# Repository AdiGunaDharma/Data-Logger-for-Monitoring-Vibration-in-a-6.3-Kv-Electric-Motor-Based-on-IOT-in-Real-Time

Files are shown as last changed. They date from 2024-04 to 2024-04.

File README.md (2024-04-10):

# Data-Logger-for-Monitoring-Vibration-in-a-6.3-Kv-Electric-Motor-Based-on-IOT-in-Real-Time
**Eagle Electronic Layout**
  1. Top Layout
Top Layout
  2. Bottom Layout
Bottom Layout
**Main**
  1. Vibration Measurement Points and Vibration Measurement Templates at Jeranjang PLTU

  2. Measurement Diagrams on Prototypes

  3. Arduino IDE Software Display and Blynk Application

  4. Sensor Data Amplifier Circuit

  5. Prototype Work System Flowchart


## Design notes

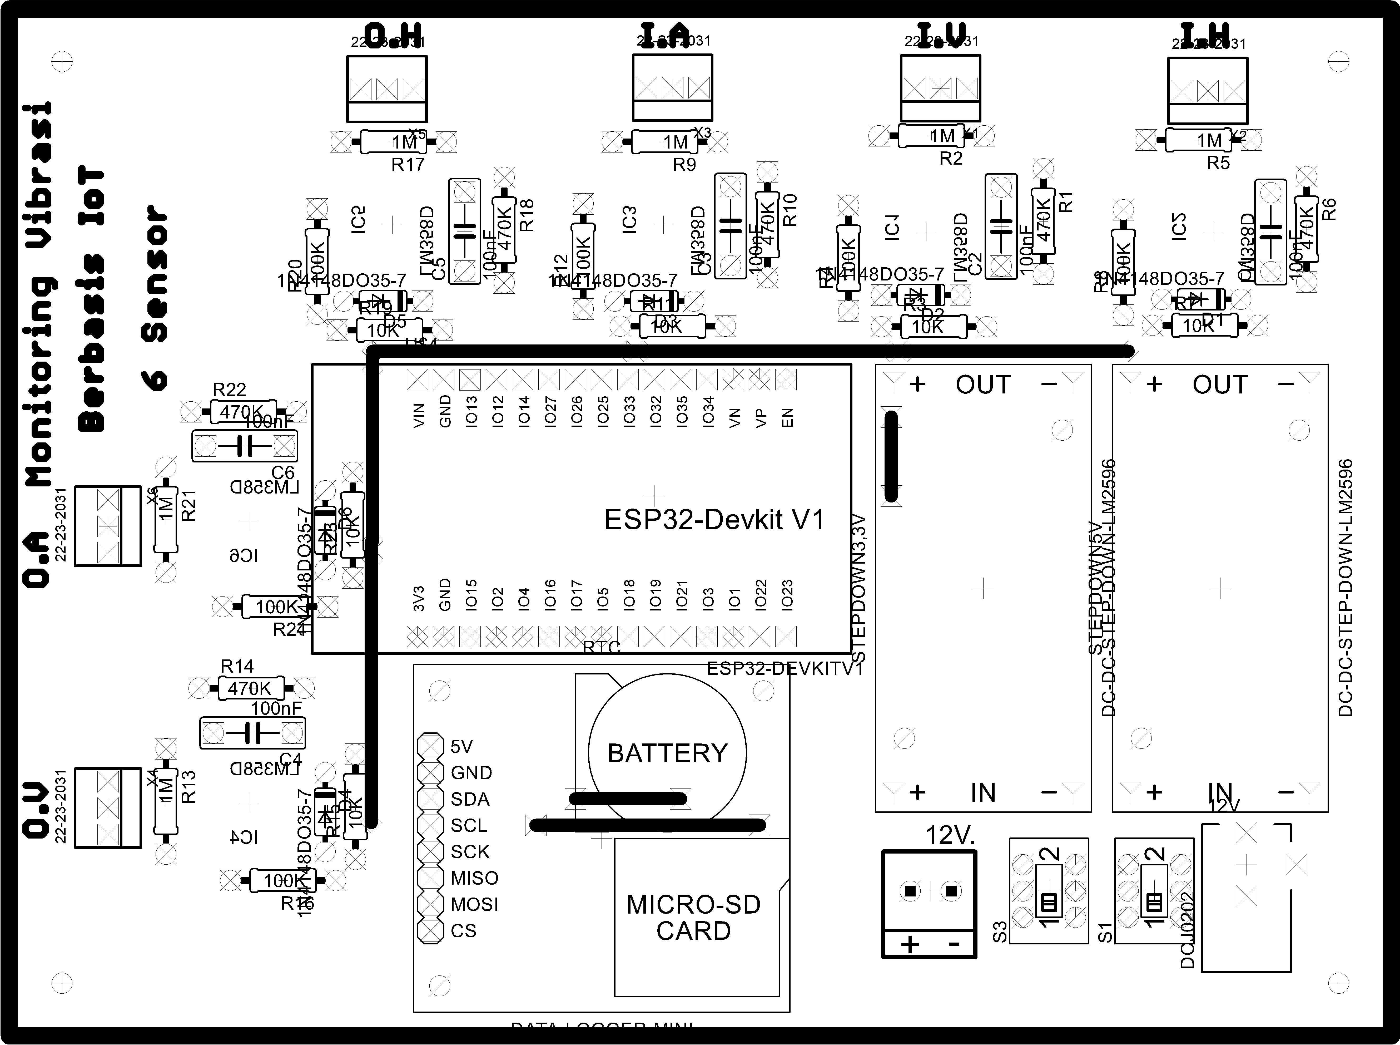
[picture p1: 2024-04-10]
Eagle Electronic Layout/Top Layout.png

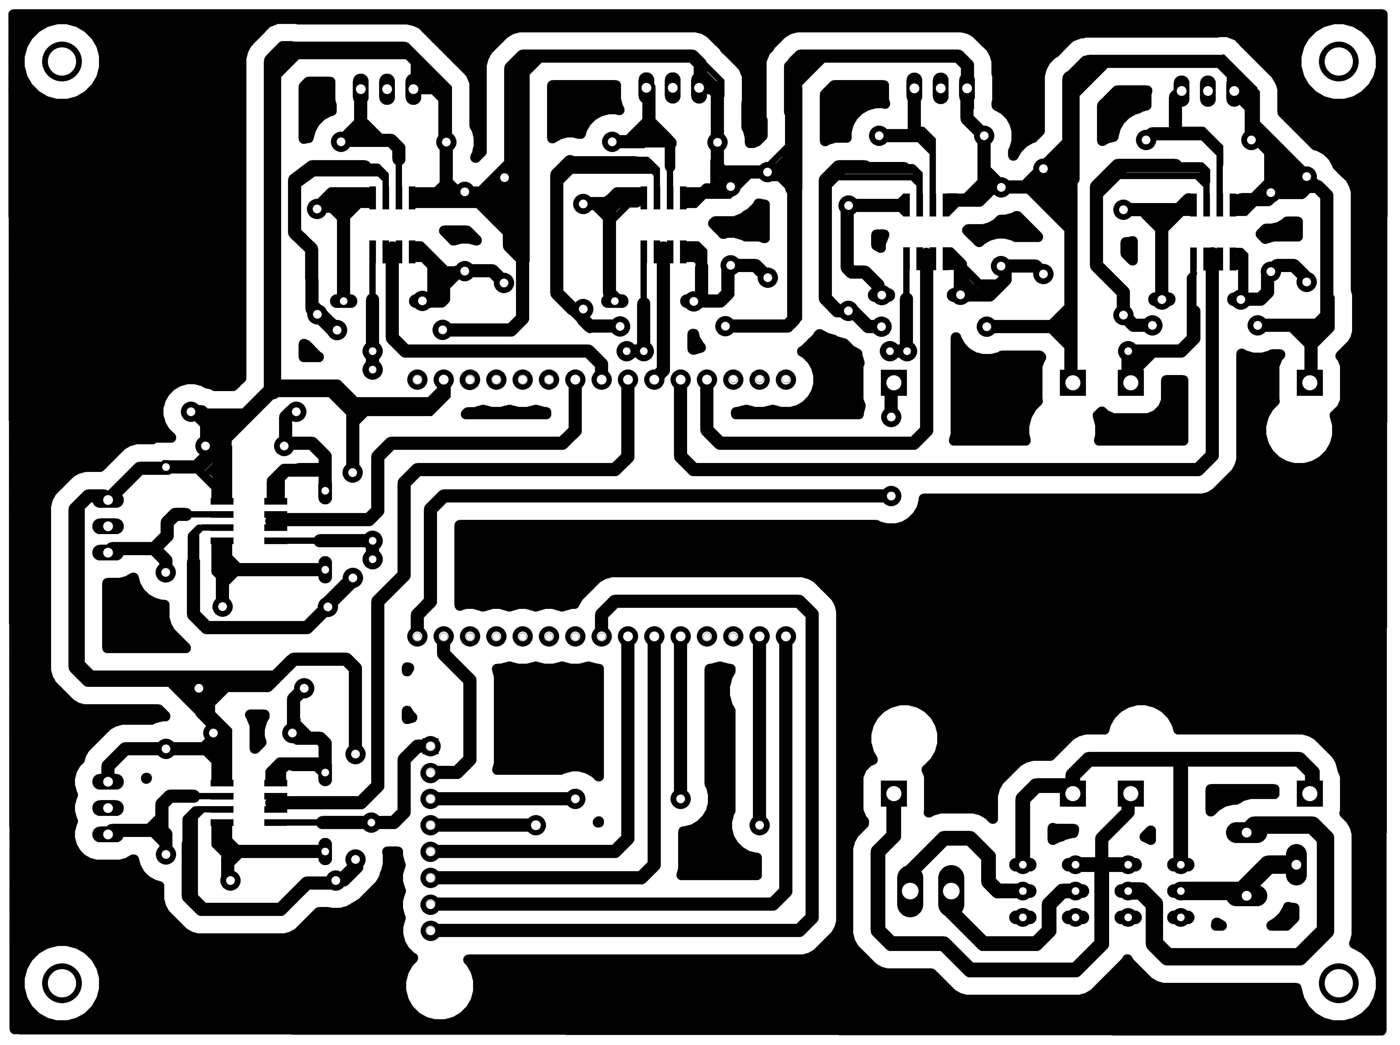
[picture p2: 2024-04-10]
Eagle Electronic Layout/Bottom Layout.png

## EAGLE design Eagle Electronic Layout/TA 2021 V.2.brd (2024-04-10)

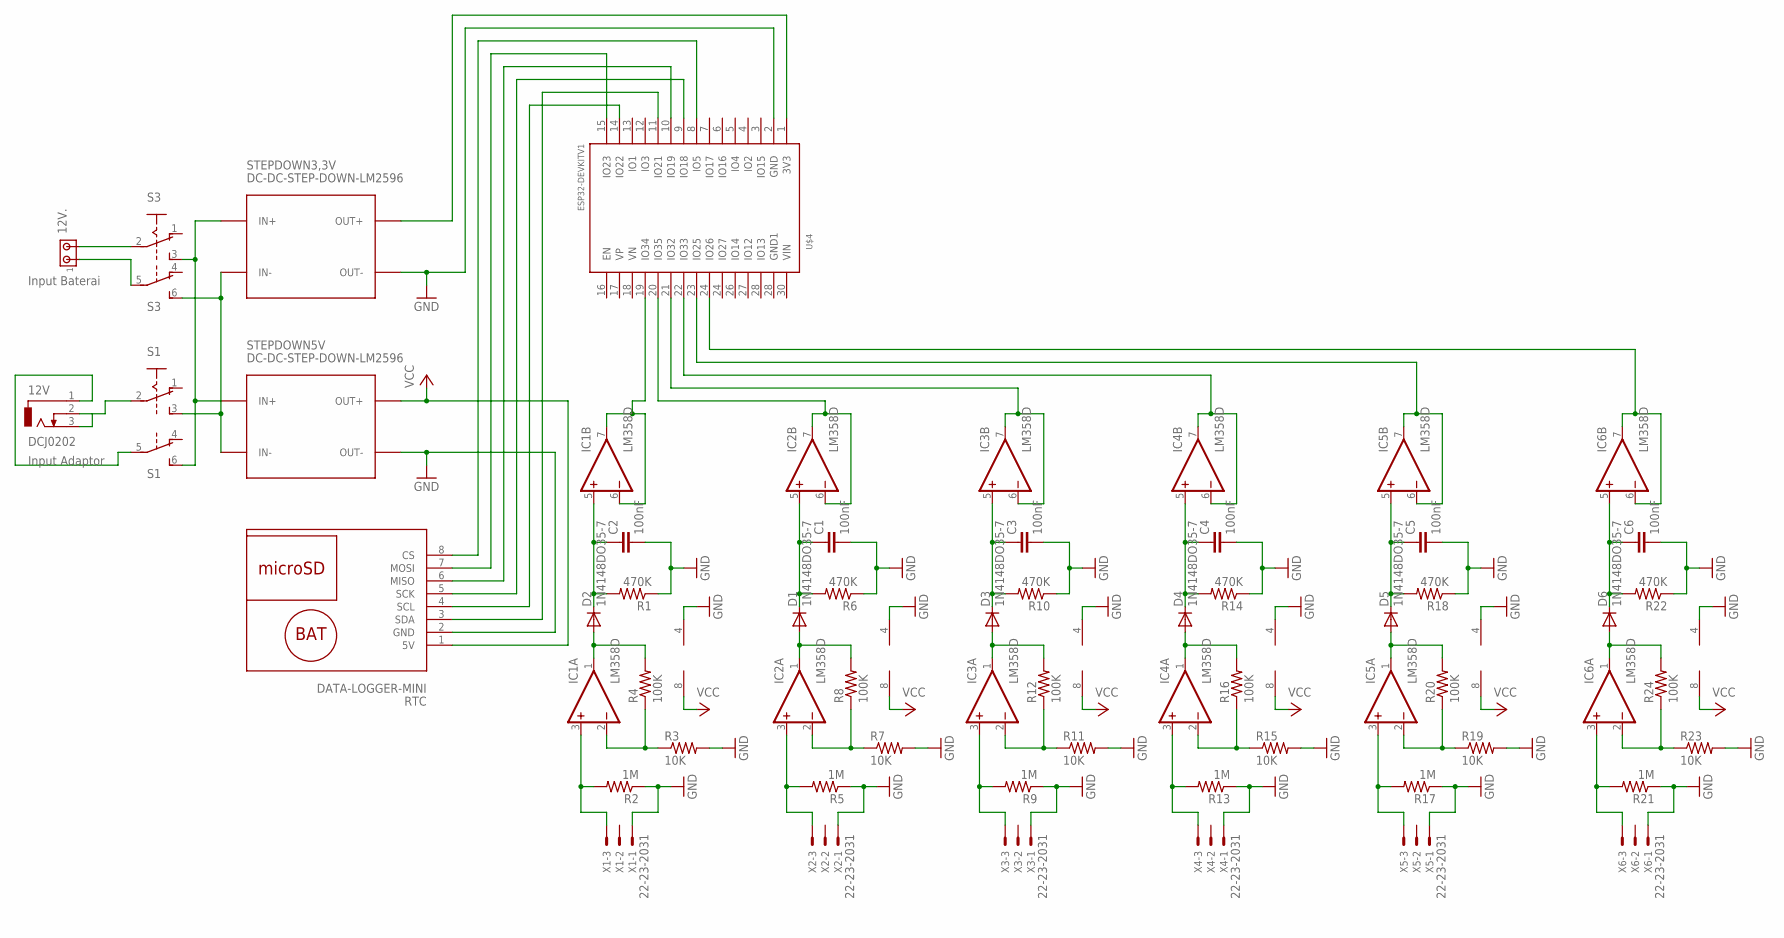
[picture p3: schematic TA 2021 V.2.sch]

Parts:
12V: DCJ0202
12V.: MTA02-156; 1X2MTA
C1, C2, C3, C4, C5, C6: 100nF; C075-032X103
D1, D2, D3, D4, D5, D6: 1N4148DO35-7; DO35-7
IC1, IC2, IC3, IC4, IC5, IC6: LM358D; SO08
R1, R6, R10, R14, R18, R22: 470K; 0207/10
R2, R5, R9, R13, R17, R21: 1M; 0207/10
R3, R7, R11, R15, R19, R23: 10K; 0207/10
R4, R8, R12, R16, R20, R24: 100K; 0207/10
RTC: DATA-LOGGER-MINI
S1, S3: A68-A31
STEPDOWN3,3V, STEPDOWN5V: DC-DC-STEP-DOWN-LM2596
U$4: ESP32DEVKITV1; ESP32-DEVKITV1
X1, X2, X3, X4, X5, X6: 22-23-2031

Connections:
unnamed: 12V..2, S3.2
unnamed: RTC.7 (MOSI), U$4.15 (IO23)
unnamed: S1.6 (S), S3.3 (S), STEPDOWN3,3V.IN+, STEPDOWN5V.IN+
unnamed: RTC.8 (CS), U$4.8 (IO5)
unnamed: 12V.2, 12V.3, S1.2
unnamed: RTC.6 (MISO), U$4.10 (IO19)
unnamed: 12V..1, S3.5
unnamed: RTC.5 (SCK), U$4.9 (IO18)
unnamed: 12V.1, S1.5
unnamed: C1.2, C2.2, C3.2, C4.2, C5.2, C6.2, IC1.4 (V-), IC2.4 (V-), IC3.4 (V-), IC4.4 (V-), IC5.4 (V-), IC6.4 (V-), R1.1, R2.1, R3.2, R5.1, R6.1, R7.2, R9.1, R10.1, R11.2, R13.1, R14.1, R15.2, R17.1, R18.1, R19.2, R21.1, R22.1, R23.2, RTC.2 (GND), STEPDOWN3,3V.OUT-, STEPDOWN5V.OUT-, U$4.2 (GND), X1.1, X2.1, X3.1, X4.1, X5.1, X6.1
unnamed: S1.3 (S), S3.6 (S), STEPDOWN3,3V.IN-, STEPDOWN5V.IN-
unnamed: IC2.6 (-IN), IC2.7 (OUT), U$4.20 (IO35)
unnamed: D1.A, IC2.1 (OUT), R8.2
unnamed: IC2.2 (-IN), R7.1, R8.1
unnamed: RTC.4 (SCL), U$4.14 (IO22)
unnamed: IC3.6 (-IN), IC3.7 (OUT), U$4.21 (IO32)
unnamed: STEPDOWN3,3V.OUT+, U$4.1 (3V3)
unnamed: IC4.6 (-IN), IC4.7 (OUT), U$4.22 (IO33)
unnamed: IC5.6 (-IN), IC5.7 (OUT), U$4.23 (IO25)
unnamed: IC6.6 (-IN), IC6.7 (OUT), U$4.24 (IO27)
unnamed: RTC.3 (SDA), U$4.11 (IO21)
unnamed: IC1.3 (+IN), R2.2, X1.3
unnamed: C1.1, D1.C, IC2.5 (+IN), R6.2
unnamed: D2.A, IC1.1 (OUT), R4.2
unnamed: IC1.2 (-IN), R3.1, R4.1
unnamed: C2.1, D2.C, IC1.5 (+IN), R1.2
unnamed: D4.A, IC4.1 (OUT), R16.2
unnamed: IC1.6 (-IN), IC1.7 (OUT), U$4.19 (IO34)
unnamed: IC2.3 (+IN), R5.2, X2.3
unnamed: D3.A, IC3.1 (OUT), R12.2
unnamed: C3.1, D3.C, IC3.5 (+IN), R10.2
unnamed: D6.A, IC6.1 (OUT), R24.2
unnamed: IC3.3 (+IN), R9.2, X3.3
unnamed: IC4.2 (-IN), R15.1, R16.1
unnamed: IC6.2 (-IN), R23.1, R24.1
unnamed: IC4.3 (+IN), R13.2, X4.3
unnamed: D5.A, IC5.1 (OUT), R20.2
unnamed: IC5.2 (-IN), R19.1, R20.1
unnamed: C5.1, D5.C, IC5.5 (+IN), R18.2
unnamed: IC5.3 (+IN), R17.2, X5.3
unnamed: IC6.3 (+IN), R21.2, X6.3
unnamed: IC3.2 (-IN), R11.1, R12.1
unnamed: C6.1, D6.C, IC6.5 (+IN), R22.2
unnamed: C4.1, D4.C, IC4.5 (+IN), R14.2
VCC: IC1.8 (V+), IC2.8 (V+), IC3.8 (V+), IC4.8 (V+), IC5.8 (V+), IC6.8 (V+), RTC.1 (5V), STEPDOWN5V.OUT+

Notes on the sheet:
Input Baterai
Input Adaptor

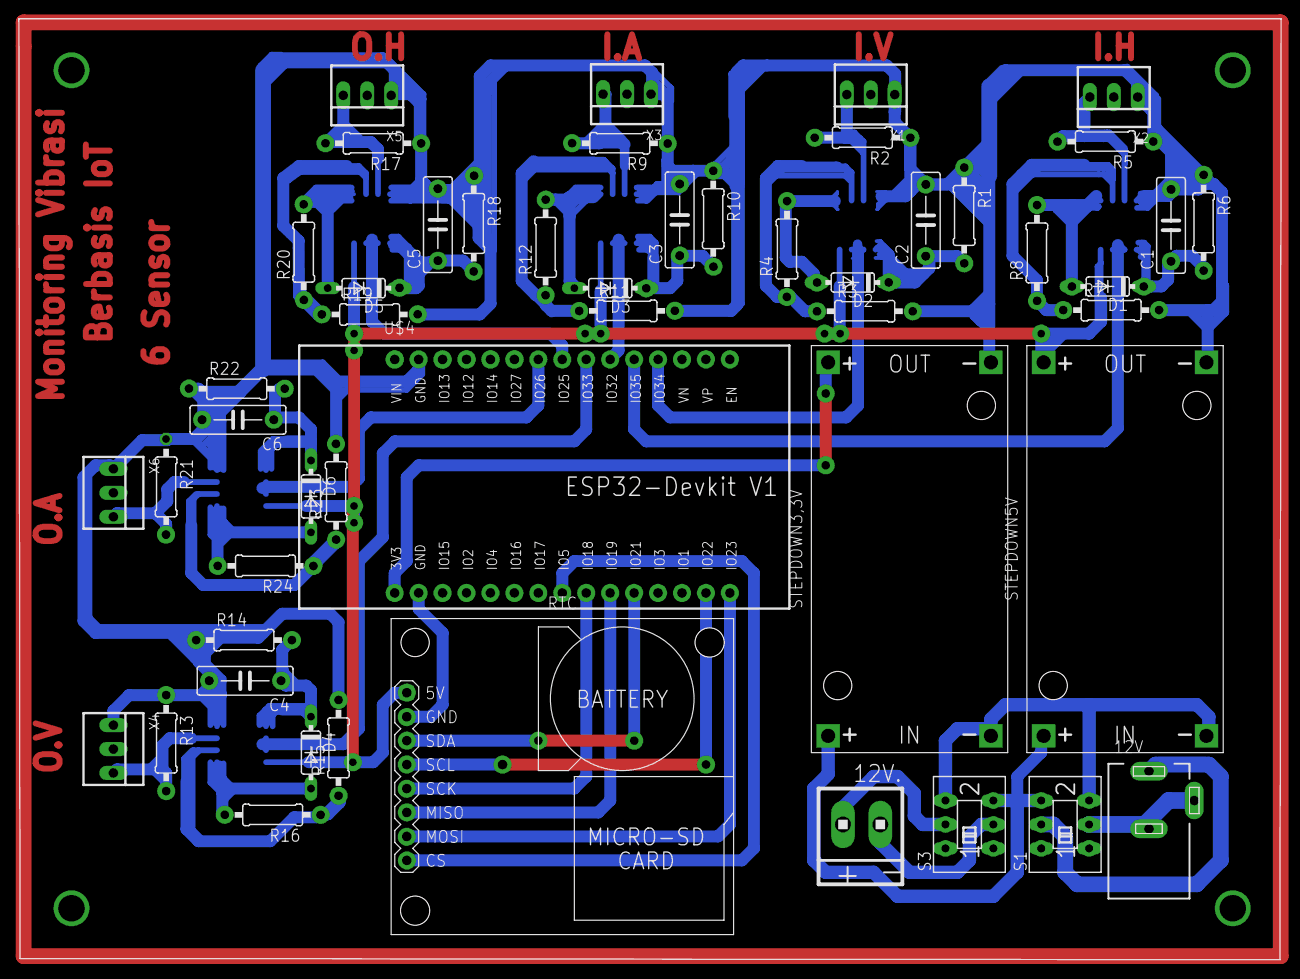
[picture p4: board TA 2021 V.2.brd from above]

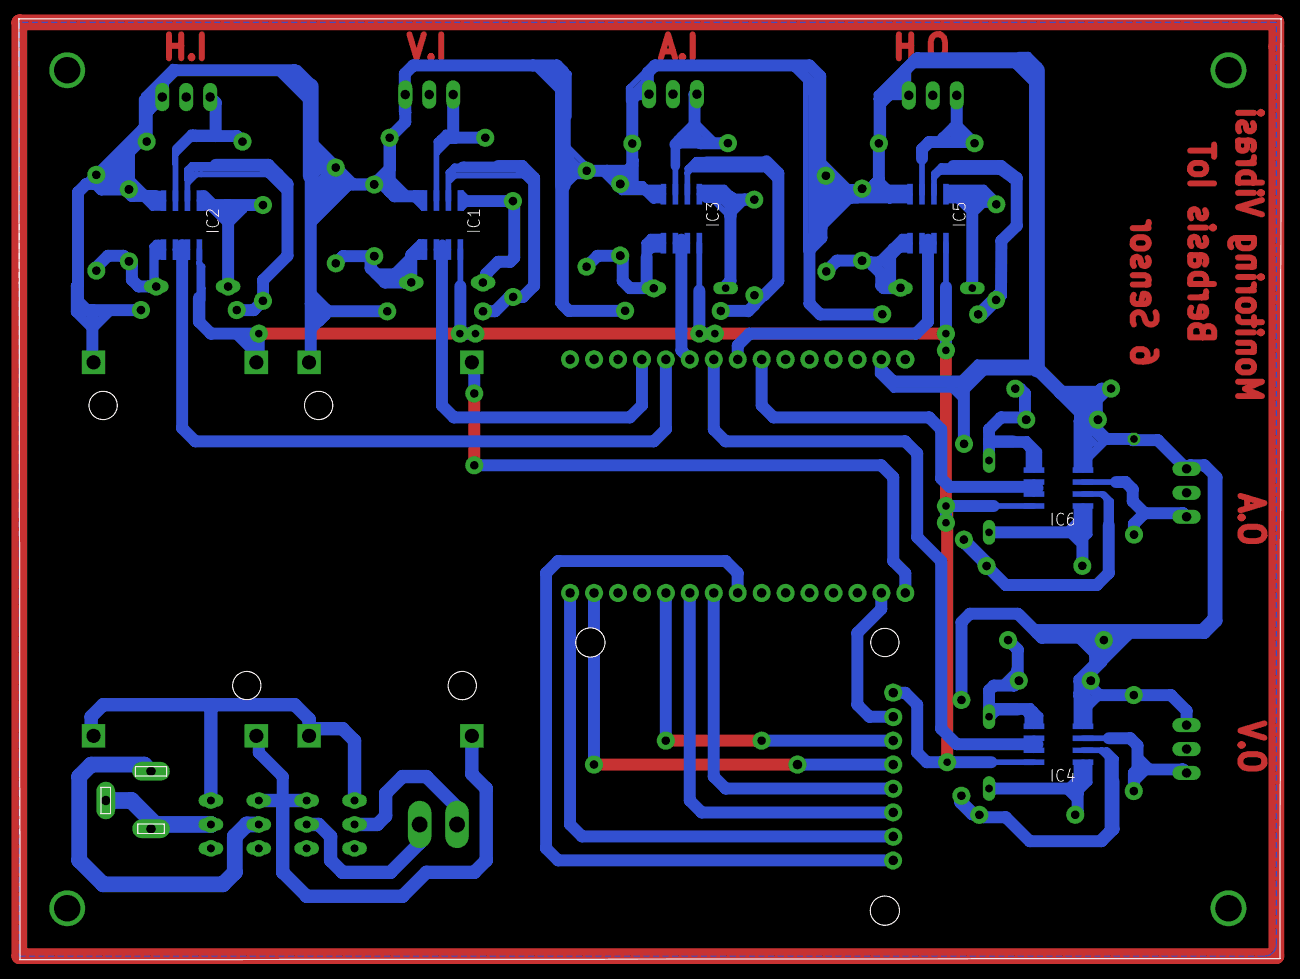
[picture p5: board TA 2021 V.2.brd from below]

Board: 2 copper layers, 133.9 x 99.8 mm, 56 parts (6 on the bottom side), 45 nets.

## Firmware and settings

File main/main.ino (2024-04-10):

#include <Wire.h>
#include <RTClib.h>
#define BLYNK_PRINT Serial
#include <Simpletimer.h>
#include <Blynk.h>
#include <WiFi.h>
#include <WiFiClient.h>
#include <BlynkSimpleEsp32.h>
#include "RTClib.h"
#include <SD.h>
#include <SPI.h>
#include "FS.h"

// You should get Auth Token in the Blynk App.
// Go to the Project Settings (nut icon).
char auth[] = "my07LK43cr97y9MoXPNs48WEfiNAayhx";
 
// Your WiFi credentials.
// Set password to "" for open networks.
char ssid[] = "Sat";
char pass[] = "agus9876";

// sensors 
const int vs1 = 34; // vibration sensor
const int vs2 = 35;
const int vs3 = 32;
const int vs4 = 33;
const int vs5 = 36;
const int vs6 = 39; 

int sdata1;
int sdata2; 
int sdata3;
int sdata4;
int sdata5;
int sdata6; // sensor data will be3 stored in this variable.
String vdata1, vdata2, vdata3, vdata4, vdata5, vdata6, tanggal= ""; 
float hasil1, hasil2, hasil3, hasil4, hasil5, hasil6;
//DS3231 Clock;
// Inisialisasi RTC & SD Card
RTC_DS1307 rtc;
char namaHari[7][12] = {"Minggu", "Senin", "Selasa", "Rabu", "Kamis", "Jumat", "Sabtu"};
File myFile;
const int CS = 5;
String hasilSD;
char cHasilSD[500];
void setup()
{
  // Debug console
  Serial.begin(115200);
   Wire.begin();
  SD.begin(CS);
  pinMode(CS, OUTPUT);
  pinMode(vs1 ,INPUT); 
  pinMode(vs2 ,INPUT); 
  pinMode(vs3 ,INPUT); 
  pinMode(vs4 ,INPUT); 
  pinMode(vs5 ,INPUT); 
  pinMode(vs6 ,INPUT); 
  Blynk.begin(auth, ssid, pass);

  // Setup a function to be called every second
//  timer.setInterval(10L,sensorvalue); // 1000L
//  setSyncProvider(RTC.get);
  if (!SD.begin(CS)) {
  Serial.println("Gagal Memuat Kartu SD");
  return;
  }
  uint8_t cardType = SD.cardType();
  if (cardType == CARD_NONE) {
  Serial.println("Tidak Ada Kartu SD");
  return;
  }
  Serial.println("Menginisialisasi kartu SD...");
  
  //RTC
  if (! rtc.begin()) {
    Serial.println("RTC TIDAK TERBACA");
    while (1);
  }

  if (! rtc.isrunning()) {
    Serial.println("RTC is NOT running!");
    rtc.adjust(DateTime(F(__DATE__), F(__TIME__)));//update rtc dari waktu komputer
  }
//    writeFile(SD, "/vibrationMonitoring.txt", " test "); //membuat file
}

void loop()
{
  Blynk.run();
Serial.println("");
  Blynk.virtualWrite(V2, "                                           "); 
   DateTime now = rtc.now();
  Serial.print(now.hour(), DEC);
  Serial.print(':');
  Serial.print(now.minute(), DEC);
  Serial.print(':');
  Serial.print(now.second(), DEC);
  Serial.print(" ");
  Serial.print(namaHari[now.dayOfTheWeek()]);
  Serial.print(',');
  Serial.print(now.day(), DEC);
  Serial.print('/');
  Serial.print(now.month(), DEC);
  Serial.print('/');
  Serial.print(now.year(), DEC);
  Serial.println();

  tanggal = tanggal + now.hour() + ":" +  now.minute()+ ":" + now.second()+ " " + namaHari[now.dayOfTheWeek()] + "," +  now.day()+ "/" + now.month()+ "/" + now.year();
  Blynk.virtualWrite(V2, tanggal);
  tanggal = ""; 
  delay(50);
  
//float konversi;
//konversi = 2;
  Serial.println("Vibrasi Motor");
  Serial.println("Inboard");
  Blynk.virtualWrite(V2,"Vibrasi Motor" );
  Blynk.virtualWrite(V2,"Inboard" );

  

 sdata1=analogRead(vs1);
 long piezo1 = map(sdata1, 0, 4095, 0, 65536);
 if(piezo1==0){ 
  hasil1=0;
 }else {
 hasil1= ((piezo1*0.000037)+0.65);
 }
  Serial.print("Vertikal: ");Serial.print(hasil1);Serial.println(" mm/s");
 // Blynk.virtualWrite(V3, piezo1);
vdata1 = vdata1 + "Vertikal: " + hasil1+ " mm/s";  
  Blynk.virtualWrite(V2, vdata1);
vdata1 = ""; 


 sdata2=analogRead(vs2);
long piezo2 = map(sdata2, 0, 4095, 0, 65536);
if(piezo2==0){
  hasil2=0;
}else{
hasil2= ((piezo2*0.000037)+0.65);
}

  Serial.print("Horizontal: ");Serial.print(hasil2);Serial.println(" mm/s");//65536
 // Blynk.virtualWrite(V3, piezo2);
vdata2 = vdata2 + "Horizontal: " + hasil2 + " mm/s";  
  Blynk.virtualWrite(V2, vdata2);
vdata2 = ""; 


sdata3=analogRead(vs3);
long piezo3 = map(sdata3, 0, 4095, 0, 65536);
if(piezo3==0){
   hasil3=0; 
}else{
 hasil3= ((piezo3*0.000037)+0.65);
}
  Serial.print("Aksial: ");Serial.print(hasil3);Serial.println(" mm/s");
 // Blynk.virtualWrite(V3, piezo3);
vdata3 = vdata3 + "Aksial: " + hasil3 + " mm/s";  
  Blynk.virtualWrite(V2, vdata3);
vdata3 = "";


Blynk.virtualWrite(V2,"Outboard" );
Serial.println("Outboard");

sdata4=analogRead(vs4);
 long piezo4 = map(sdata4, 0, 4095, 0, 65536);
 if(piezo4==0){
hasil4=0;
 }else{
 hasil4= ((piezo4*0.000037)+0.65);
 }
  Serial.print("Vertikal: ");Serial.print(hasil4);Serial.println(" mm/s");
  //Blynk.virtualWrite(V3, piezo4);
vdata4 = vdata4 + "Vertikal: " + hasil4 + " mm/s";  
  Blynk.virtualWrite(V2, vdata4);
vdata4 = ""; 


sdata5=analogRead(vs5);
long piezo5 = map(sdata5, 0, 4095, 0, 65536);
if(piezo5==0){
hasil5=0;
}else{
 hasil5= ((piezo5*0.000037)+0.65);
}
  Serial.print("Horizontal: ");Serial.print(hasil5);Serial.println(" mm/s");
  //Blynk.virtualWrite(V3, piezo5);
vdata5 = vdata5 + "Horizontal: " + hasil5 + " mm/s";  
  Blynk.virtualWrite(V2, vdata5);
vdata5 = ""; 

sdata6=analogRead(vs6);
long piezo6 = map(sdata6, 0, 4095, 0, 65536);
  if(piezo6==0){
 hasil6=0;
  }else{
hasil6= ((piezo6*0.000037)+0.65);
}
  Serial.print("Aksial: ");Serial.print(hasil6);Serial.println(" mm/s");
 // Blynk.virtualWrite(V3, piezo6);
vdata6 = vdata6 + "Aksial: " + hasil6 + " mm/s";  
  Blynk.virtualWrite(V2, vdata6);
vdata6 = ""; 

 
 hasilSD = hasilSD  +  now.hour() + ":" + now.minute() + ":" + now.second() + "  " + namaHari[now.dayOfTheWeek()] + "," + now.day() + "/" + now.month() + "/" + now.year() + "\n" + "Vibrasi Motor" + "\n" + "Inboard" + "\n" + "Vertikal: " + hasil1 + " mm/s" + "\n" + "Horizontal: " + hasil2 + " mm/s" + "\n" + "Aksial: " + hasil3 + " mm/s" + "\n" + "Outboard" + "\n" +  "Vertikal: " + hasil4 + " mm/s" + "\n" + "Horizontal: " + hasil5 + " mm/s" + "\n" + "Aksial: " + hasil6 + " mm/s" + "\n" + "\n"; 
  hasilSD.toCharArray(cHasilSD, 500);     //menjadikan hasilSD menjadi char array
  appendFile(SD, "/vibrationMonitoring.txt", cHasilSD);   //menambahkan data ke file
  hasilSD = ""; 
  delay(10000);
}
void writeFile(fs::FS &fs, const char * path, const char * message){
    Serial.printf("Writing file: %s\n", path);

    File file = fs.open(path, FILE_WRITE);
    if(!file){
        Serial.println("Failed to open file for writing");
        return;
    }
    if(file.print(message)){
        Serial.println("File written");
    } else {
        Serial.println("Write failed");
    }
    file.close();
}

void appendFile(fs::FS &fs, const char * path, const char * message){
    Serial.printf("Appending to file: %s\n", path);

    File file = fs.open(path, FILE_APPEND);
    if(!file){
        Serial.println("Failed to open file for appending");
        return;
    }
    if(file.print(message)){
        Serial.println("Message appended");
    } else {
        Serial.println("Append failed");
    }
    file.close();
}

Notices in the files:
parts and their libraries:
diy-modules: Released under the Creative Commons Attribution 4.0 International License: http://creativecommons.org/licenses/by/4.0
